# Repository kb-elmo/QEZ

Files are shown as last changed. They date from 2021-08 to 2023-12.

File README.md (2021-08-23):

# QEZ

[][cc-by-nc-sa]<a href="https://ko-fi.com/kb_elmo">kofibadge</a>

### A seamless, gasketmounted QAZ-like 40% keyboard

header

---

[STEP files for the case](case/)

[KiCAD PCB files](pcb/)

[Gerbers for PCB production](pcb/gerbers/)

[JLCPCB BOM](pcb/fab/qez_bom_jlc.csv)

[JLCPCB CPL](pcb/fab/qez_cpl_jlc.csv)

[Vial-QMK firmware](firmware/)

---

This work is licensed under a
[Creative Commons Attribution-NonCommercial-ShareAlike 4.0 International License][cc-by-nc-sa].

[][cc-by-nc-sa]

[cc-by-nc-sa]: http://creativecommons.org/licenses/by-nc-sa/4.0/
[cc-by-nc-sa-image]: https://licensebuttons.net/l/by-nc-sa/4.0/88x31.png
[cc-by-nc-sa-shield]: https://img.shields.io/badge/License-CC%20BY--NC--SA%204.0-lightgrey.svg

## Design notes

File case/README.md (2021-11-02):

# QEZ case

### These files are meant for 3D printing only! 

They are not suitable for CNC machining and trying to use them for that will most likely result in failure of the parts.

For assembly you need 4x m2.5x4mm screws for the case and 8x 2mm thick foam strips for the "gaskets" to mount the plate.

---

### Supported layouts

Plate 1  
layout1

Plate 2  
layout2

Plate 3  
layout3

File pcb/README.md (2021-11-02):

# QEZ PCB

### Features

- Powered by an Atmega32u2
- Basic ESD and overvoltage protection
- Centered USB type-C port for a detachable cable
- Multiple layout options (see below)
- Fully programmable using [QMK](https://qmk.fm) and [Vial](https://get.vial.today)

---

### Supported layouts

layout1
layout2
layout3

---

### Preview

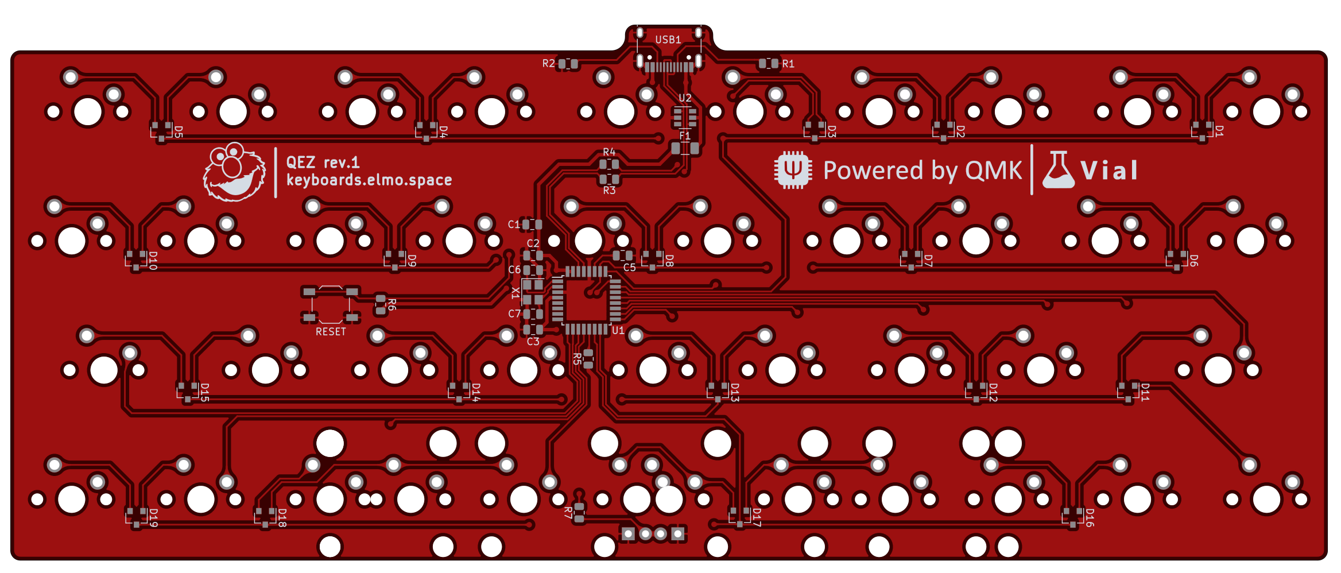
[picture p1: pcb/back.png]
pcb_back

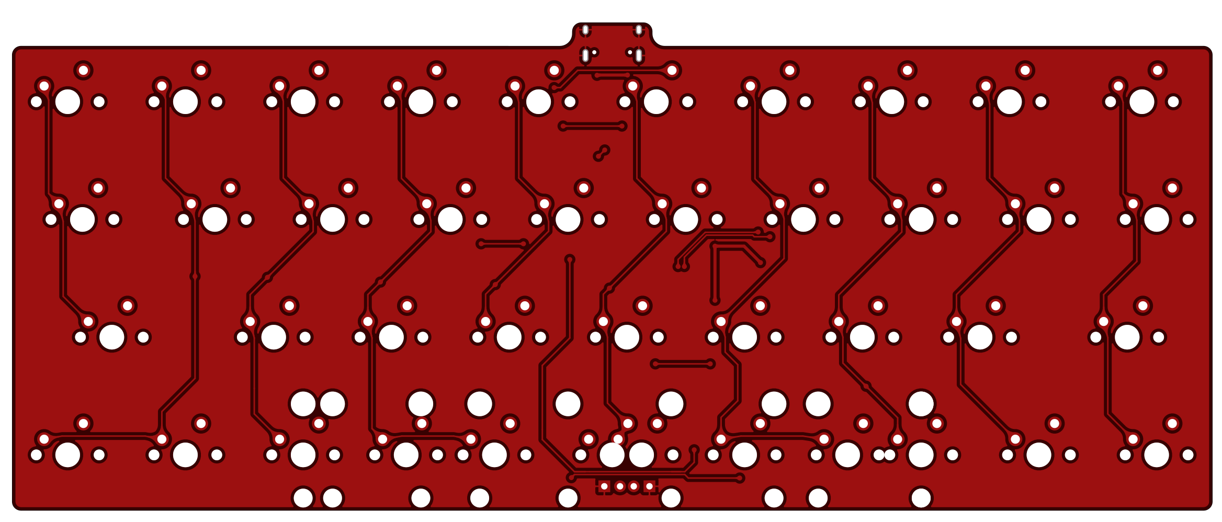
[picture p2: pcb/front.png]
pcb_front


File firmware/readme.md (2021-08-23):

# QEZ

qez

A seamless gasketmounted QAZ-like 40% keyboard

* Keyboard Maintainer: [kb-elmo](https://github.com/kb-elmo)
* Hardware Supported: QEZ rev.1 PCB
* Hardware Availability: [Open source project](https://github.com/kb-elmo/QEZ)

Make example for this keyboard (after setting up your build environment):

    make kb_elmo/qez:default

Flashing example for this keyboard:

    make kb_elmo/qez:default:flash

See the [build environment setup](https://docs.qmk.fm/#/getting_started_build_tools) and the [make instructions](https://docs.qmk.fm/#/getting_started_make_guide) for more information. Brand new to QMK? Start with our [Complete Newbs Guide](https://docs.qmk.fm/#/newbs).

## Bootloader

* **Bootmagic reset**: Hold down the top left key and plug in the keyboard
* **Physical reset button**: Briefly press the button labeled "RESET" on the back of the PCB

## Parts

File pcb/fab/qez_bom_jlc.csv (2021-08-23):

Comment | Designator | Footprint | LCSC Part #
10uF | C1 | C_0805_2012Metric | C91245
0.1uF | C2,C3 | C_0805_2012Metric | C49678
1uF | C5 | C_0805_2012Metric | C28323
22pF | C6,C7 | C_0805_2012Metric | C1804
D_Small | D1,D5,D4,D3,D2,D6,D10,D9,D8,D7,D11,D15,D14,D13,D12,D19,D18,D16,D17 | D_SOT-23_ANK | C68978
Polyfuse_Small | F1 | Fuse_1206_3216Metric | C69688
5.1k | R1,R2 | R_0805_2012Metric | C27834
22 | R3,R4 | R_0805_2012Metric | C17561
10k | R5,R6 | R_0805_2012Metric | C17414
1.5k | R7 | R_0805_2012Metric | C4310
SW_Push | RESET | SW_SPST_TL3342 | C318884
ATmega32U2-AU | U1 | TQFP-32_7x7mm_P0.8mm | C618733
SRV05-4 | U2 | SOT-23-6 | C85364
USB_C_Receptacle_USB2.0 | USB1 | USB_C_Receptacle_HRO_TYPE-C-31-M-12 | C165948
Crystal_GND24_Small | X1 | Crystal_SMD_3225-4Pin_3.2x2.5mm | C13738

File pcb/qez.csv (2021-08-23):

Comment | Designator | Footprint | LCSC
10uF | C1 | Capacitor_SMD:C_0805_2012Metric | C91245
0.1uF | C2,C3 | Capacitor_SMD:C_0805_2012Metric | C49678
1uF | C5 | Capacitor_SMD:C_0805_2012Metric | C28323
22pF | C6,C7 | Capacitor_SMD:C_0805_2012Metric | C1804
D_Small | D1,D2,D3,D4,D5,D6,D7,D8,D9,D10,D11,D12,D13,D14,D15,D16,D17,D18,D19 | custom_parts:D_SOT-23_ANK | C68978
Polyfuse_Small | F1 | Fuse:Fuse_1206_3216Metric | C69688
MX-NoLED | MX10,MX11 | MX_Only:MXOnly-1.25U-NoLED
MX-NoLED | MX1,MX2,MX3,MX4,MX5,MX6,MX7,MX8,MX9,MX12,MX13,MX14,MX15,MX16,MX17,MX18,MX19,MX20,MX22,MX23,MX24,MX25,MX26,MX27,MX28,MX29,MX31,MX32,MX36,MX37,MX38 | MX_Only:MXOnly-1U-NoLED
MX-NoLED | MX21 | MX_Only:MXOnly-1.75U-NoLED
MX-NoLED | MX30 | MX_Only:MXOnly-1.5U-NoLED
MX-NoLED | MX33 | MX_Only:MXOnly-2.75U-ReversedStabilizers-NoLED
MX-LED | MX34 | MX_Only:MXOnly-1.25U
MX-NoLED | MX35,MX39 | MX_Only:MXOnly-2.25U-ReversedStabilizers-NoLED
MX-NoLED | MX40 | MX_Only:MXOnly-2U-ReversedStabilizers-NoLED
MX-LED | MX41 | custom_parts:MXOnly-6.25U-ReversedStabilizers-flippedLED
5.1k | R1,R2 | Resistor_SMD:R_0805_2012Metric | C27834
22 | R3,R4 | Resistor_SMD:R_0805_2012Metric | C17561
10k | R5,R6 | Resistor_SMD:R_0805_2012Metric | C17414
1.5k | R7 | Resistor_SMD:R_0805_2012Metric | C4310
SW_Push | RESET1 | Button_Switch_SMD:SW_SPST_TL3342 | C318884
ATmega32U2-AU | U1 | Package_QFP:TQFP-32_7x7mm_P0.8mm | C618733
SRV05-4 | U2 | Package_TO_SOT_SMD:SOT-23-6 | C85364
USB_C_Receptacle_USB2.0 | USB1 | Connector_USB:USB_C_Receptacle_HRO_TYPE-C-31-M-12 | C165948
Crystal_GND24_Small | X1 | Crystal:Crystal_SMD_3225-4Pin_3.2x2.5mm | C13738

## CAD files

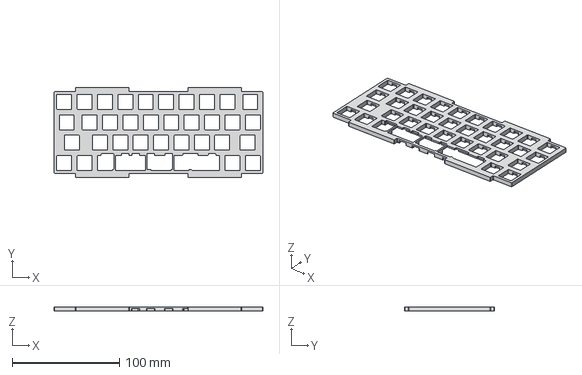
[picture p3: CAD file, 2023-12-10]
case/qez_universal_plate_4mm.step
195.3 x 84.2 x 4.00 mm

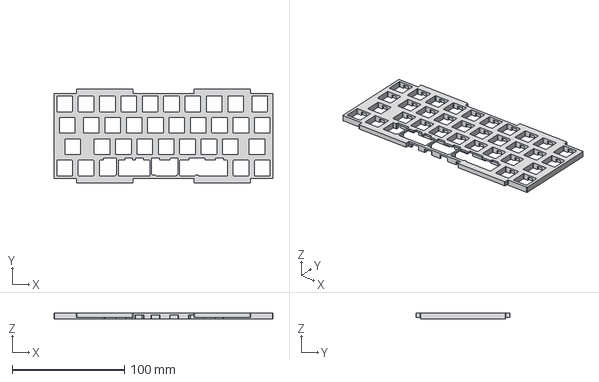
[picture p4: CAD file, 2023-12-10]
case/qez_universal_plate_5mm.step
195.3 x 84.2 x 5.00 mm

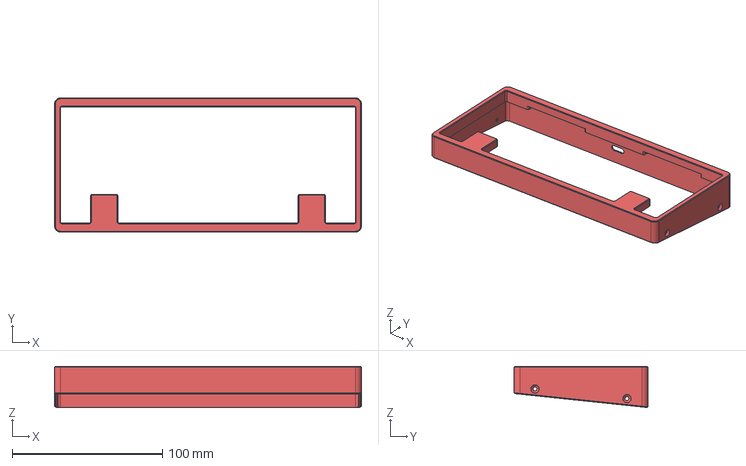
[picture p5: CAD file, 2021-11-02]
case/qez_top_wkl.step
204.3 x 89.2 x 27.3 mm

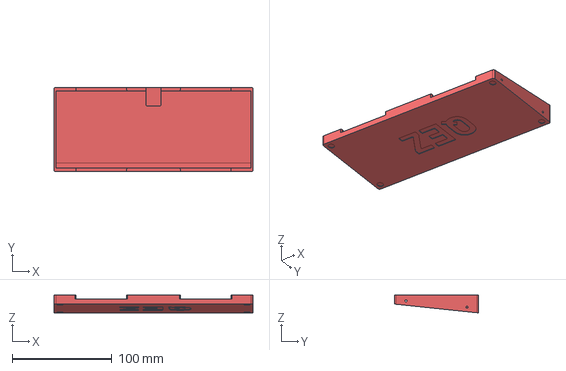
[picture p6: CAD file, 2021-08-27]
case/qez_bottom.step
199.9 x 84.8 x 17.9 mm

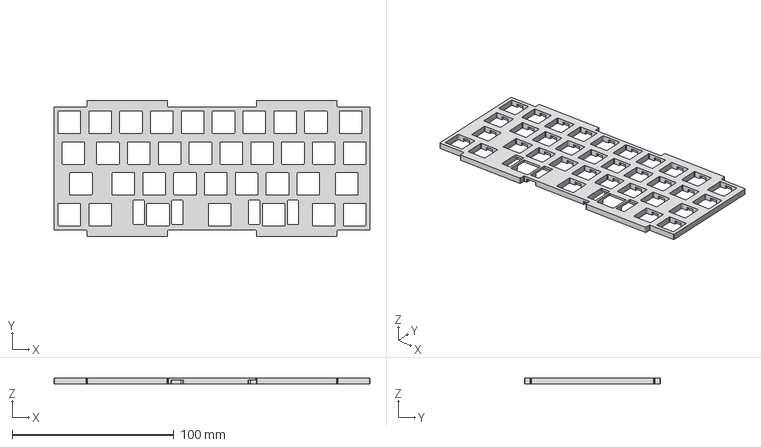
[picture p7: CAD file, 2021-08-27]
case/qez_plate2.step
195.3 x 84.2 x 4.00 mm

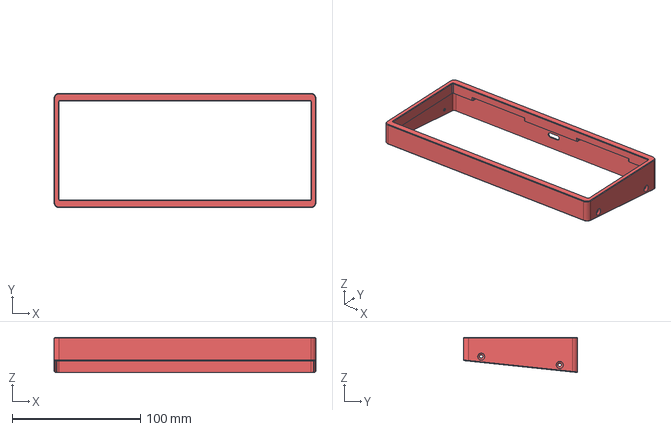
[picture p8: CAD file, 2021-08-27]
case/qez_top.step
204.3 x 89.2 x 27.3 mm

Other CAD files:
case/qez_top_hhkb.step
case/qez_plate1.step
case/qez_plate3.step

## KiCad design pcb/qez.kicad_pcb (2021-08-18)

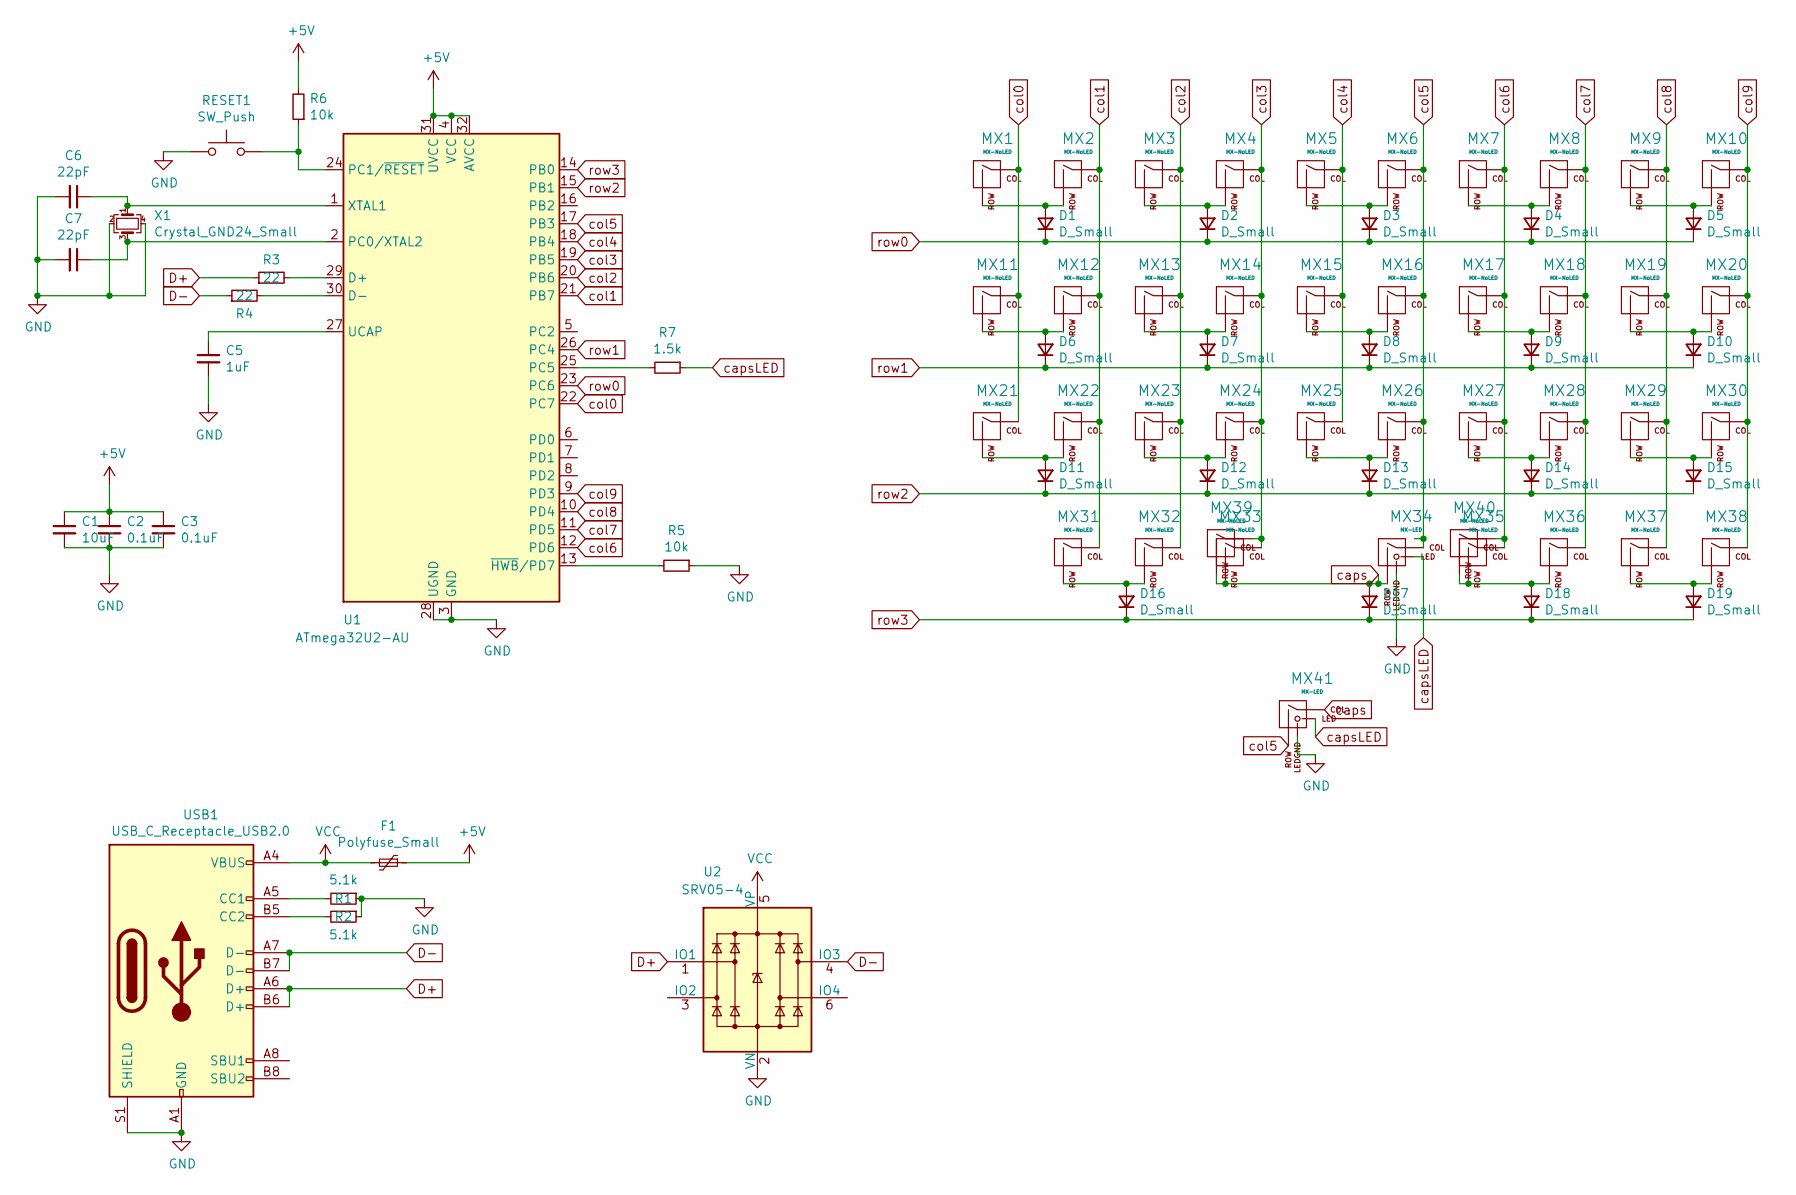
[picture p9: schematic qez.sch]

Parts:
C1: 10uF; C_0805_2012Metric; LCSC C91245
C2, C3: 0.1uF; C_0805_2012Metric; LCSC C49678
C5: 1uF; C_0805_2012Metric; LCSC C28323
C6, C7: 22pF; C_0805_2012Metric; LCSC C1804
D1, D2, D3, D4, D5, D6, D7, D8, D9, D10, D11, D12, D13, D14, D15, D16, D17, D18, D19: D_Small; D_SOT-23_ANK; LCSC C68978
F1: Polyfuse_Small; Fuse_1206_3216Metric; LCSC C69688
MX1, MX2, MX3, MX4, MX5, MX6, MX7, MX8, MX9, MX12, MX13, MX14, MX15, MX16, MX17, MX18, MX19, MX20, MX22, MX23, MX24, MX25, MX26, MX27, MX28, MX29, MX31, MX32, MX36, MX37, MX38: MX-NoLED; MXOnly-1U-NoLED
MX10, MX11: MX-NoLED; MXOnly-1.25U-NoLED
MX21: MX-NoLED; MXOnly-1.75U-NoLED
MX30: MX-NoLED; MXOnly-1.5U-NoLED
MX33: MX-NoLED; MXOnly-2.75U-ReversedStabilizers-NoLED
MX34: MX-LED; MXOnly-1.25U
MX35, MX39: MX-NoLED; MXOnly-2.25U-ReversedStabilizers-NoLED
MX40: MX-NoLED; MXOnly-2U-ReversedStabilizers-NoLED
MX41: MX-LED; MXOnly-6.25U-ReversedStabilizers-flippedLED
R1, R2: 5.1k; R_0805_2012Metric; LCSC C27834
R3, R4: 22; R_0805_2012Metric; LCSC C17561
R5, R6: 10k; R_0805_2012Metric; LCSC C17414
R7: 1.5k; R_0805_2012Metric; LCSC C4310
RESET1: SW_Push; SW_SPST_TL3342; LCSC C318884
U1: ATmega32U2-AU; TQFP-32_7x7mm_P0.8mm
U2: SRV05-4; SOT-23-6; LCSC C85364
USB1: USB_C_Receptacle_USB2.0; USB_C_Receptacle_HRO_TYPE-C-31-M-12; LCSC C165948
X1: Crystal_GND24_Small; Crystal_SMD_3225-4Pin_3.2x2.5mm; LCSC C13738

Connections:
+5V: C1.1, C2.1, C3.1, F1.1, R6.2, U1.4 (VCC), U1.31 (UVCC), U1.32 (AVCC)
D+: R3.1, U2.1 (IO1), USB1.A6 (D+), USB1.B6 (D+)
D-: R4.1, U2.4 (IO3), USB1.A7 (D-), USB1.B7 (D-)
GND: C1.2, C2.2, C3.2, C5.2, C6.2, C7.2, MX34.4 (LEDGND), MX41.4 (LEDGND), R1.1, R2.1, R5.1, RESET1.1, U1.3 (GND), U1.28 (UGND), U2.2 (VN), USB1.A1 (GND), USB1.A12 (GND), USB1.B1 (GND), USB1.B12 (GND), USB1.S1 (SHIELD), X1.2, X1.4; also elsewhere on the board
unnamed: C5.1, U1.27 (UCAP)
unnamed: C6.1, U1.1 (XTAL1), X1.1
unnamed: C7.1, U1.2 (PC0/XTAL2), X1.3
unnamed: D1.2 (A), MX1.2 (ROW), MX2.2 (ROW)
unnamed: D2.2 (A), MX3.2 (ROW), MX4.2 (ROW)
unnamed: D3.2 (A), MX5.2 (ROW), MX6.2 (ROW)
unnamed: D4.2 (A), MX7.2 (ROW), MX8.2 (ROW)
unnamed: D5.2 (A), MX9.2 (ROW), MX10.2 (ROW)
unnamed: D6.2 (A), MX11.2 (ROW), MX12.2 (ROW)
unnamed: D7.2 (A), MX13.2 (ROW), MX14.2 (ROW)
unnamed: D8.2 (A), MX15.2 (ROW), MX16.2 (ROW)
unnamed: D9.2 (A), MX17.2 (ROW), MX18.2 (ROW)
unnamed: D10.2 (A), MX19.2 (ROW), MX20.2 (ROW)
unnamed: D11.2 (A), MX21.2 (ROW), MX22.2 (ROW)
unnamed: D12.2 (A), MX23.2 (ROW), MX24.2 (ROW)
unnamed: D13.2 (A), MX25.2 (ROW), MX26.2 (ROW)
unnamed: D14.2 (A), MX27.2 (ROW), MX28.2 (ROW)
unnamed: D15.2 (A), MX29.2 (ROW), MX30.2 (ROW)
unnamed: D16.2 (A), MX31.2 (ROW), MX32.2 (ROW)
unnamed: D18.2 (A), MX35.2 (ROW), MX36.2 (ROW), MX40.2 (ROW)
unnamed: D19.2 (A), MX37.2 (ROW), MX38.2 (ROW)
unnamed: R1.2, USB1.A5 (CC1)
unnamed: R2.2, USB1.B5 (CC2)
unnamed: R3.2, U1.29 (D+)
unnamed: R4.2, U1.30 (D-)
unnamed: R5.2, U1.13 (~HWB~/PD7)
unnamed 30: R6.1, RESET1.2, U1.24 (PC1/~RESET); also elsewhere on the board
unnamed: R7.2, U1.25 (PC5)
VCC: F1.2, U2.5 (VP), USB1.A4 (VBUS), USB1.A9 (VBUS), USB1.B4 (VBUS), USB1.B9 (VBUS)
caps: D17.2 (A), MX33.2 (ROW), MX34.2 (ROW), MX39.2 (ROW), MX41.1 (COL)
capsLED: MX34.3 (LED), MX41.3 (LED), R7.1
col0: MX1.1 (COL), MX11.1 (COL), MX21.1 (COL), U1.22 (PC7)
col1: MX2.1 (COL), MX12.1 (COL), MX22.1 (COL), MX31.1 (COL), U1.21 (PB7)
col2: MX3.1 (COL), MX13.1 (COL), MX23.1 (COL), MX32.1 (COL), U1.20 (PB6)
col3: MX4.1 (COL), MX14.1 (COL), MX24.1 (COL), MX33.1 (COL), MX39.1 (COL), U1.19 (PB5)
col4: MX5.1 (COL), MX15.1 (COL), MX25.1 (COL), U1.18 (PB4)
col5: MX6.1 (COL), MX16.1 (COL), MX26.1 (COL), MX34.1 (COL), MX41.2 (ROW), U1.17 (PB3)
col6: MX7.1 (COL), MX17.1 (COL), MX27.1 (COL), MX35.1 (COL), MX40.1 (COL), U1.12 (PD6)
col7: MX8.1 (COL), MX18.1 (COL), MX28.1 (COL), MX36.1 (COL), U1.11 (PD5)
col8: MX9.1 (COL), MX19.1 (COL), MX29.1 (COL), MX37.1 (COL), U1.10 (PD4)
col9: MX10.1 (COL), MX20.1 (COL), MX30.1 (COL), MX38.1 (COL), U1.9 (PD3)
row0: D1.1 (K), D2.1 (K), D3.1 (K), D4.1 (K), D5.1 (K), U1.23 (PC6)
row1: D6.1 (K), D7.1 (K), D8.1 (K), D9.1 (K), D10.1 (K), U1.26 (PC4)
row2: D11.1 (K), D12.1 (K), D13.1 (K), D14.1 (K), D15.1 (K), U1.15 (PB1)
row3: D16.1 (K), D17.1 (K), D18.1 (K), D19.1 (K), U1.14 (PB0)

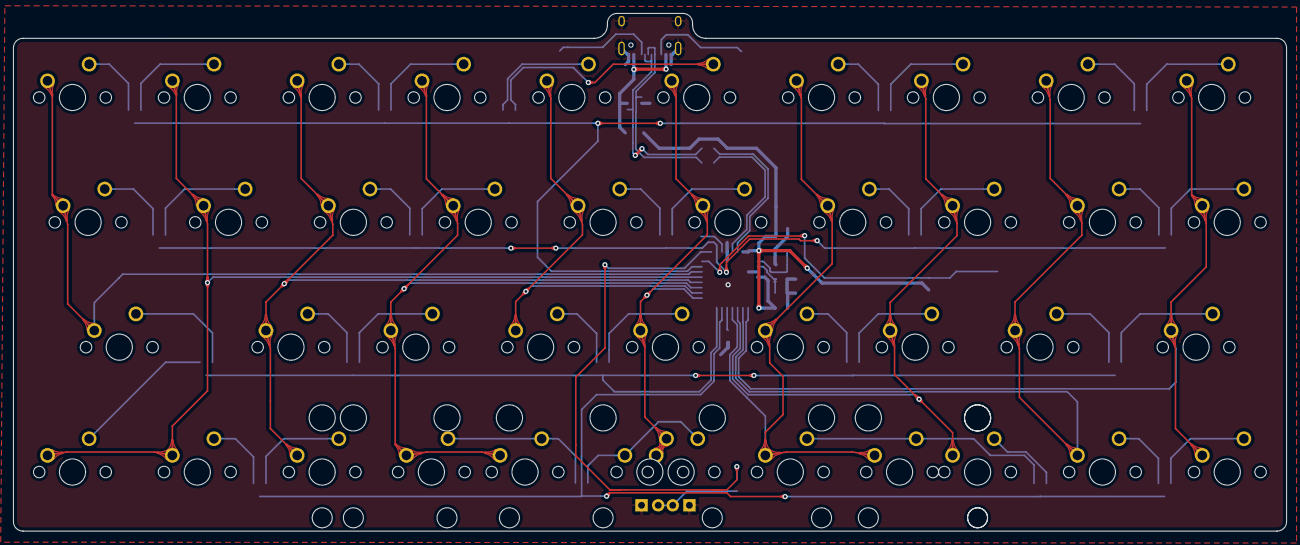
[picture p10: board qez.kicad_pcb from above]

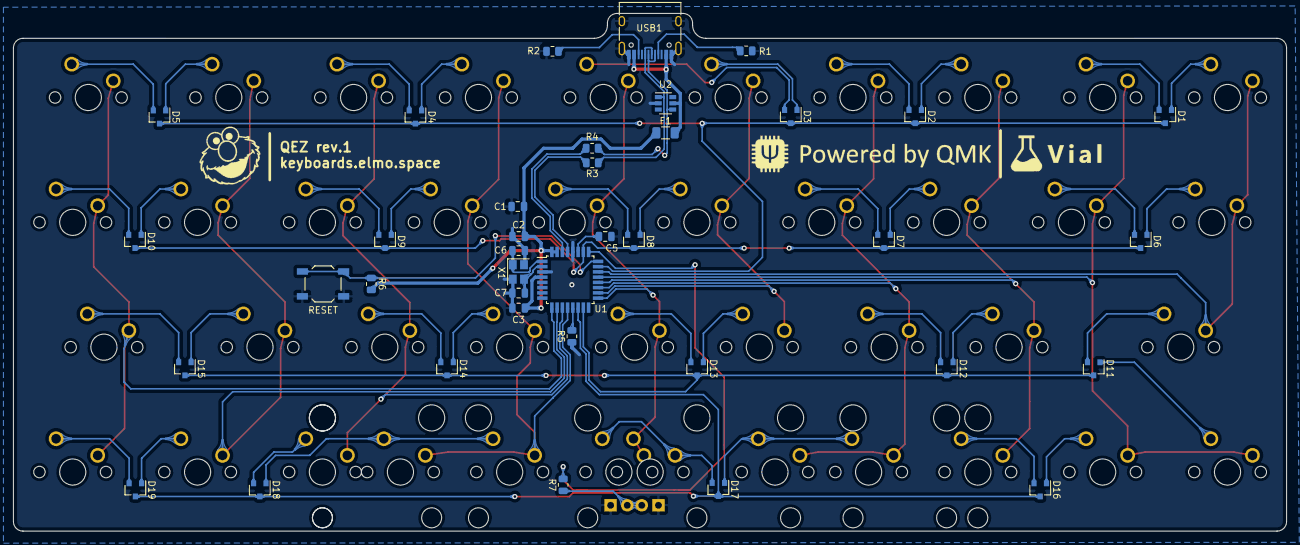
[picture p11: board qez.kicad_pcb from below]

Board: 2 copper layers, 194.3 x 79.0 mm, 79 parts (38 on the bottom side), 49 nets.

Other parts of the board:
RESET: SW_Push; SW_SPST_TL3342

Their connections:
GND: RESET.1; also elsewhere on the board
unnamed 30: RESET.2; also elsewhere on the board

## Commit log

2021-08-18 remove gerber zip
2021-08-23 add MCU part number for JLC
    [qez.csv, qez_bom_jlc.csv]
2021-08-27 fix step files
    [qez_bottom.step, qez_plate.step, qez_plate1.step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]
2021-11-02 add hhkb top
    [qez_top_hhkb.step]
2021-11-02 add WKL top
    [qez_top_wkl.step]
2023-12-10 Added universal plate in 4mm (like other plates) and 5mm (real thickplate, no gap between PCB and plate)
    [qez_universal_plate_4mm.step, qez_universal_plate_5mm.step]

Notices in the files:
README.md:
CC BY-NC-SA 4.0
